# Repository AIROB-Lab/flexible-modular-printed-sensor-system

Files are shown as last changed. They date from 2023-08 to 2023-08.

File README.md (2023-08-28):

# Development of a flexible, modular, and wearable 3D-printed sensor system

## Project Overview
This repository presents the results of the development of a flexible, modular and wearable 3D printed sensor system for the Delsys Inc. Avanti sensors [1] in the scope of the Research Lab of Enes Bektürk at Assistive Intelligent Robotics Lab, AIBE, FAU. Marc-Anton Scheidl and Fabio Egle supervised the project.
The goal was to utilize 3D printing technology to create a versatile, adaptable and wearable sensor system. The primary focus is on developing a system that can accommodate EMG sensors for wearable robotics applications while also being capable of integrating other sensor types. The aim is to produce a sensor system that is both flexible and modular, allowing for easy customization and scalability to meet various research and industry needs. The stated objective of this Research Lab was:
* Acquisition of Electromyography (EMG)-Data in a multi-channel configuration
* Secure and strong fit of multiple Delsys Inc. Avanti sensors [8]
* Modular and/or stretchable design to house a variable number of sensors
* Wearable below and above the elbow and below and above the knee!
* No usage of adhesive materials
* Strong fit to dedicated extremities during activities of daily living
* Simple and easy donning and doffing
* Minimum assembly required
* Comfortable fit

In the scope of this work, previous scientific work has been investigated, including [2][3]. While both solutions have advantages for specific use cases, none could satisfy all stated objectives.

## Results
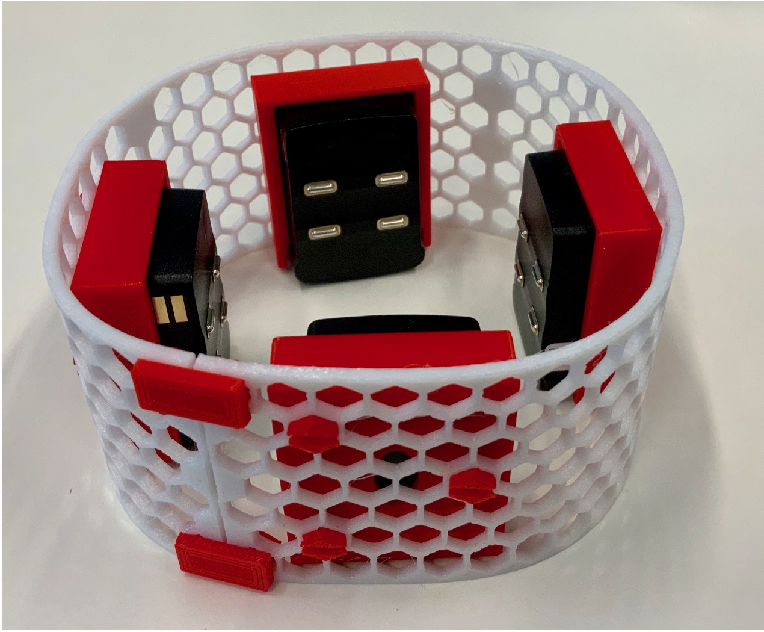
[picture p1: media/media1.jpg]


*Picture of the closed sensorband with sensors attached*

### Hexagon Band
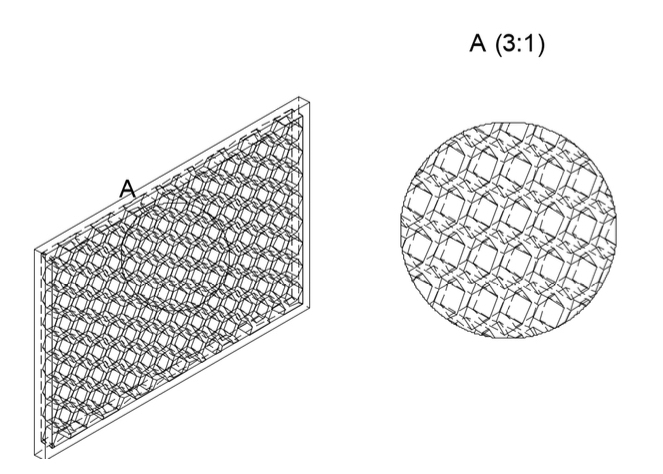
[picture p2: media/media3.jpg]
Image showing the hexagon band


*CAD construction of hexagon structured band*

Due to the requirements, TPU was chosen as the base material was the most suitable option. Furthermore, the hexagonal structure was selected based on the requirements, as it was best suited to withstand the forces acting on the band. Different band lengths were used to adjust the band to various anatomical structures with different diameters. As the 3D printer limited the overall length, the maximum printing length of the printer was divided by four to serve as the base length for the band. This base length was then mirrored and multiplied to create the band for the sensor holder. This method could easily adjust different band lengths to fit a wide range of anatomical structures.

### Wristband Closure
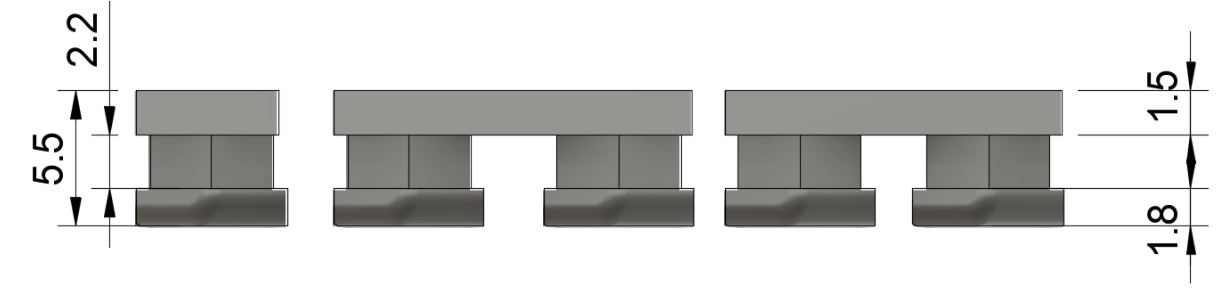
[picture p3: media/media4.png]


*Technical illustration of the different types of Mounting Brackets for (left to right) vertically connecting two bands, connecting four bands or two rows end-to-end at the corner of each band end, and horizontal connecting of two bands*

Various Mounting brackets/ holders were designed to fulfill different functions and had other geometric arrangements. Different Holders were needed to fulfill the following functions (see also Figure 2):
1. Housing-band attachment: To attach the Sensor Housing to the band.
2. Extending the band length: Holders that serve to extend the band between the bands.
3. Connect Sensor Rows: Holders that vertically connect a possible second row of sensors on a separate band.
4. Wristband closure: A Mounting Bracket that connects the end of one band with the underlying band.

### Sensor Housing
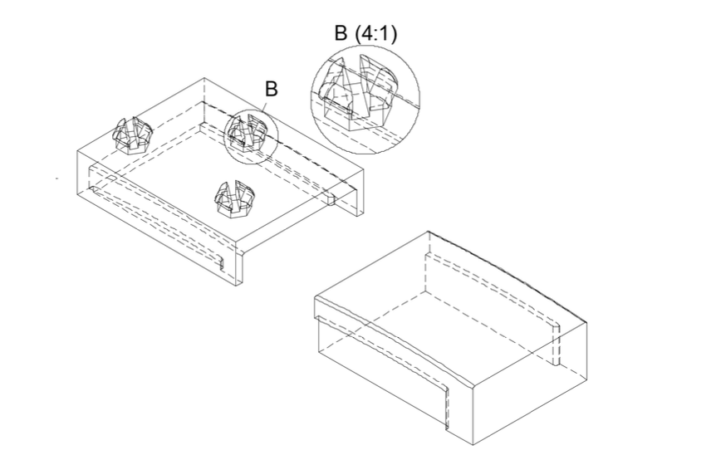
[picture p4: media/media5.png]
Image showing Sensor Housing


*CAD Construction of Sensor Holder and the Sensor*

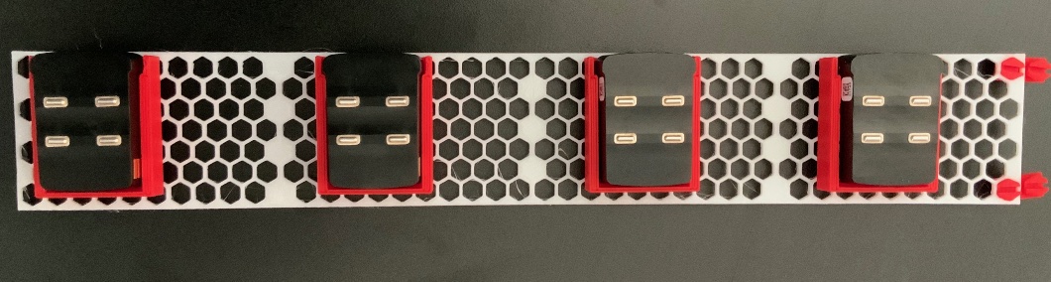
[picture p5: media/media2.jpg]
Image showing assembled wristband


*Picture of the open Sensorband with Sensors attached*

Unlike the band and the holder, the Sensor Holder is subject to minimal forces during movement, and therefore, no special elasticity is required. The main requirement is that the sensor remains stable in its anchorage throughout the process. Therefore, PLA is used for the Sensor Housing.

# Printer and Settings
The Raise3D Pro3 was used for all prints. PLA prints (Sensor Housing, Wristband Closure), as well as TPU prints (Hexagon Band, Wristband Closure), were printed with standard settings and the [original filament libraries](https://www.ideamaker.io/ofpMaterials.html) for Ideamaker.

# References
[1] Trigno Avanti Technical Specifications. https://delsys.com/trigno-avanti/#techspecs. Accessed on June 3, 2023. Delsys Inc., Accessed 2023.

[2] Ulysse Côté-Allard et al. “A Low-Cost, Wireless, 3-D-Printed Custom Armband for sEMG Hand Gesture Recognition”. In: Sensors 19.12 (Jan. 2019). Number: 12 Publisher: Multidisciplinary Digital Publishing Institute, p. 2811. ISSN: 1424-8220. DOI: 10.3390/s19122811. URL: https://www.mdpi.com/1424-8220/19/12/2811 (visited on 11/27/2022).

[3] Manuela Gomez-Correa and David Cruz-Ortiz. “Low-Cost Wearable Band Sensors of Surface Electromyography for Detecting Hand Movements”. eng. In: Sensors (Basel, Switzerland) 22.16 (Aug. 2022), p. 5931. ISSN: 1424-8220. DOI: 10. 3390/s22165931.

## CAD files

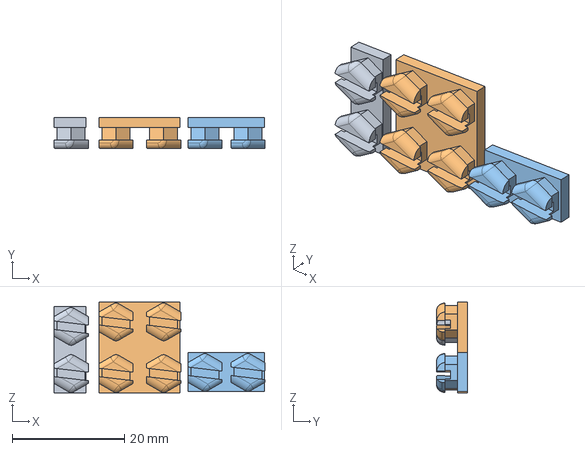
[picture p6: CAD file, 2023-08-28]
CAD_files/Connectors/Connectors.step
37.6 x 5.50 x 16.2 mm
Komponente2
Komponente3

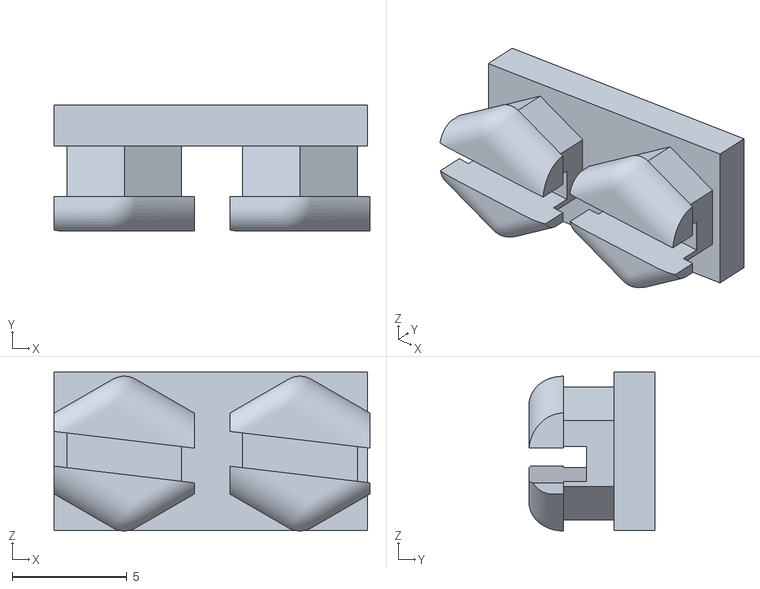
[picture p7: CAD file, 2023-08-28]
CAD_files/Connectors/STLs/Connector_horizontal.stl
13.7 x 5.50 x 6.91

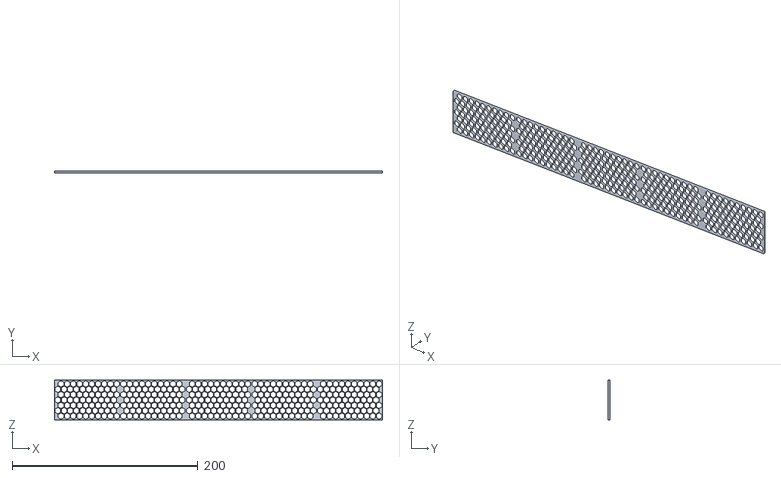
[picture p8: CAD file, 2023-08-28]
CAD_files/Sensorband_Housing/STLs/Sensorband_hexagon_x5.stl
353.3 x 1.80 x 43.0

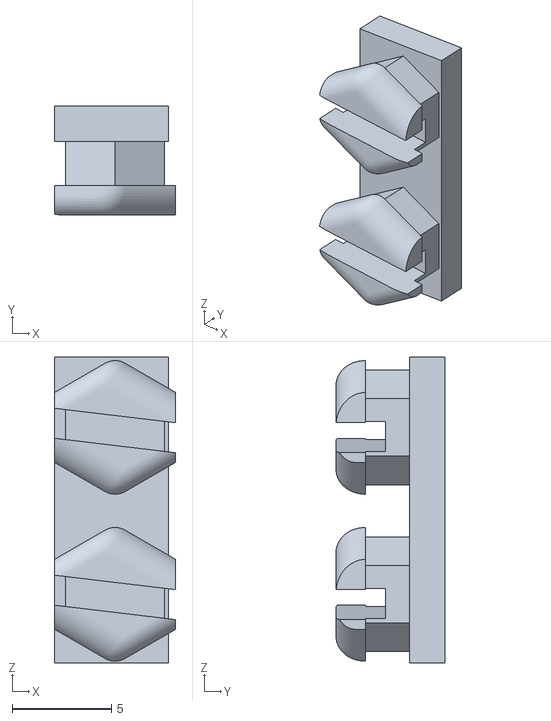
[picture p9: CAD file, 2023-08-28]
CAD_files/Connectors/STLs/Connector_vertical.stl
6.10 x 5.50 x 15.4

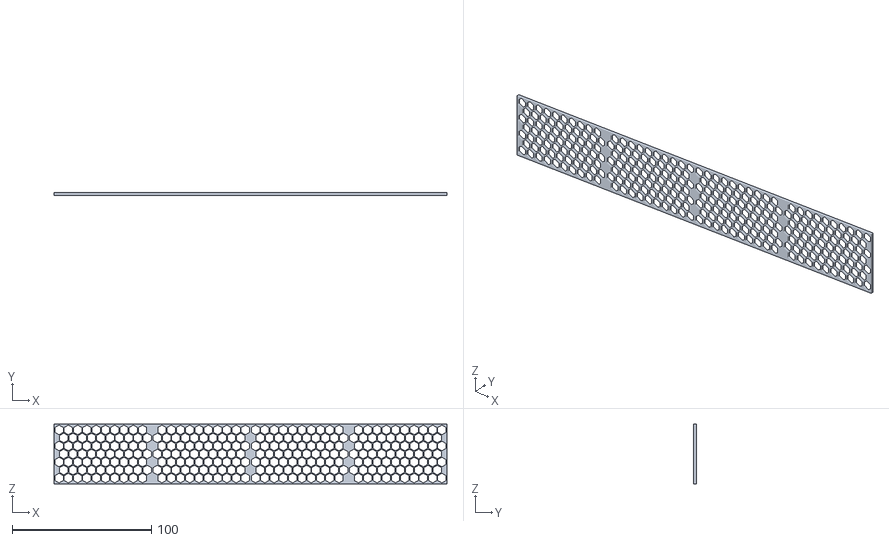
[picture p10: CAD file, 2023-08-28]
CAD_files/Sensorband_Housing/STLs/Sensorband_hexagon_x4.stl
282.7 x 1.80 x 43.0

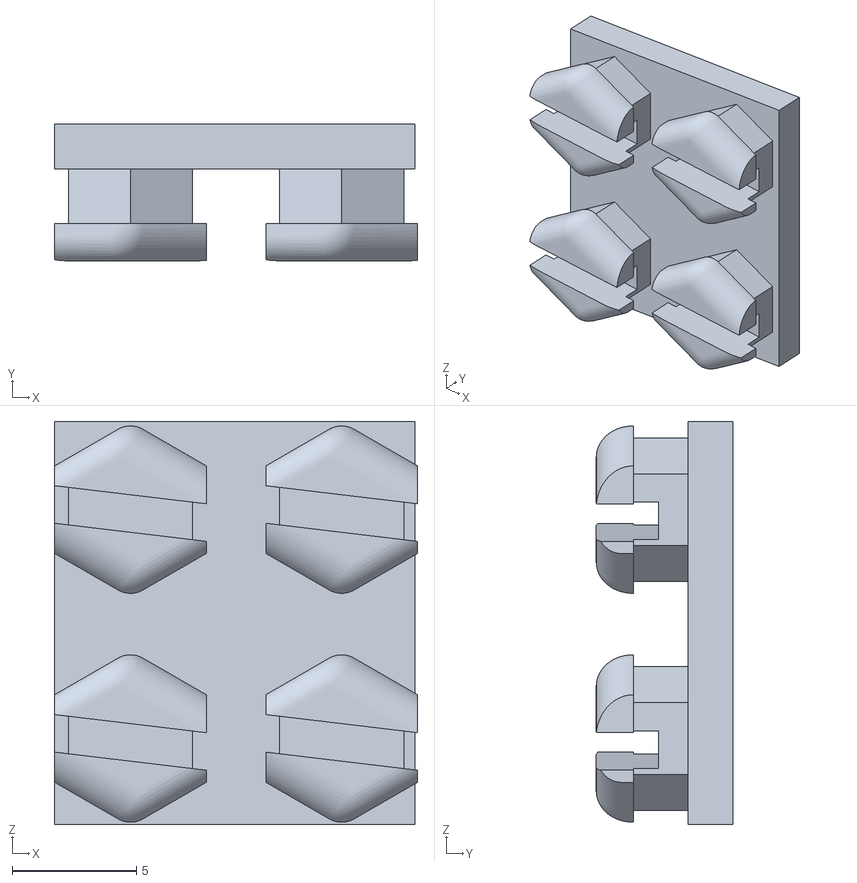
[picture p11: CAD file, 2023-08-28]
CAD_files/Connectors/STLs/Connector_quad.stl
14.6 x 5.50 x 16.2

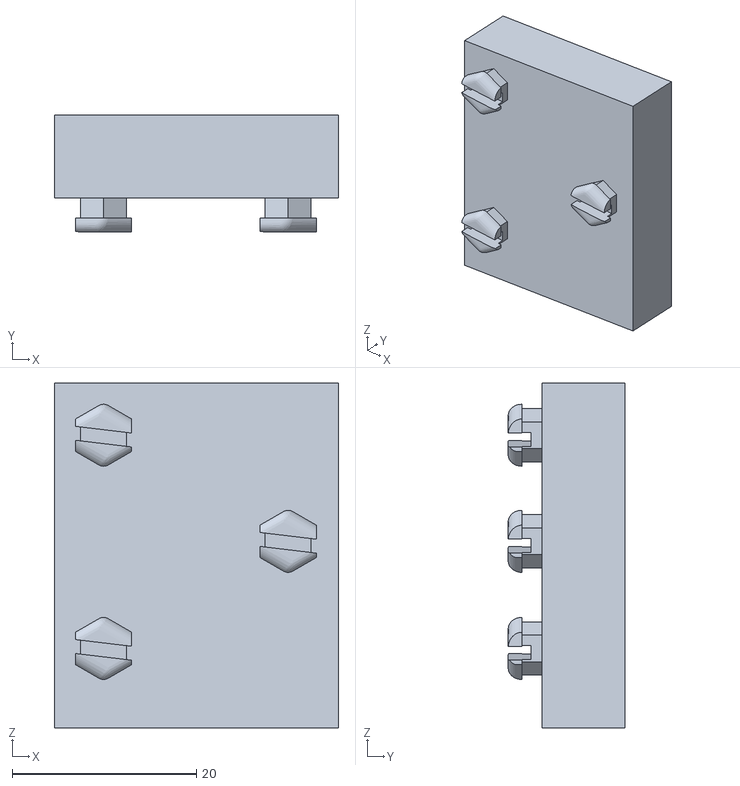
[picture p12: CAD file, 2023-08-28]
CAD_files/Sensorband_Housing/STLs/Sensor_housing.stl
30.8 x 12.7 x 37.4

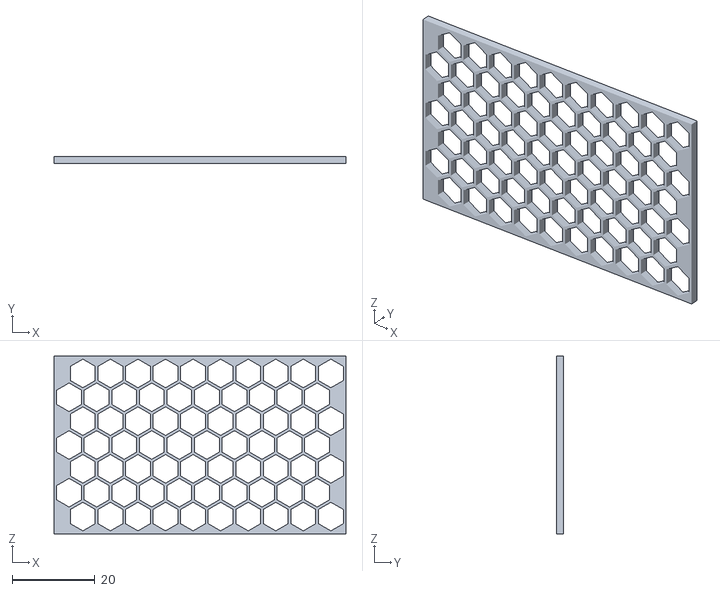
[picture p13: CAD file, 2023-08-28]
CAD_files/Sensorband_Housing/STLs/Sensorband_hexagon_x1.stl
70.7 x 1.80 x 43.0
